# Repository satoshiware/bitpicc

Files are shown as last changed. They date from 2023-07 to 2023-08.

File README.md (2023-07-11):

# Quarter Stick
Bitcoin & microcurrency (SHA256D) Miner - Single ASIC Chip - USB 4.0 (Type C) - Built w\ Eagle

Many thanks to Sidehack (gekkoscience), Kano (cgminer), and Skot (bitaxe)!!
Even though they did not contribute to this project directly, It would not have been possible without their pioneering efforts.

## Setup for Testing Chips
https://youtube.com/watch?v=U-l4Qi08SAI&feature=share

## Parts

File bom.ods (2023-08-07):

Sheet: bm1397
Part | Qty | Value | Device | Package | Manufacture | Mfr. # | Comments | DNP
C1, C2, C3, C4, C5, C6, C7, C8, C9, C10 | 10 | 0.1uF | Ceramic Capacitor | 0402 | KEMET | C0402C104M4PACTU | 16V, X5R, 20%
C13, C14, C15 | 3 | 10uF | Ceramic Capacitor | 0805 | Samsung | CL21A106KOQNNNG | 16V, X5R, 10%
C11, C12, C16, C17, C18, C19, C20, C21, C22, C23, C24, C25, C26, C27, C28, C29 | 16 | 1uF | Ceramic Capacitor | 0603 | KEMET | C0603C105K4RACTU | 16V, X7R, 10%
C30, C31 | 2 | 47pF | Ceramic Capacitor | 0402 | Murata | GRT1555C1H470JA02D | 50V, C0G (NP0), 5%
C32 | 1 | TBD | Capacitor | 1210 | TBD | TBD | Fan | DNP
C33, C34, C35 | 3 | 47uF | Ceramic Capacitor | 1210 | Murata | GRM32EC81C476KE15L | 16V, X6S, 10%, High Capacitance \w Low ESR
C36, C37, C38 | 3 | 100uF | Ceramic Capacitor | 1210 | Murata | GRM32EC70J107ME15K | 6.3V, X7S, 20%, High Capacitance \w Low ESR
C39 | 1 | 3.3nF | Ceramic Capacitor | 0402 | Murata | GRM155R71H332KA01D | 50V, X7R, 10%, DC-DC “Soft-Start”
C40 | 1 | 180pF | Ceramic Capacitor | 0402 | Murata | GRM1555C1H181JA01J | 50V, C0G (NP0), 5%, DC-DC “Compensation Feedback”
C41 | 1 | 1.5nF | Ceramic Capacitor | 0402 | Murata | GRM155R71H152JA01D | 50V, X7R, 5%, DC-DC “Compensation Feedback”
C42 | 1 | 470pF | Ceramic Capacitor | 0402 | Murata | GCM1555C1H471JA16D | 50V, C0G (NP0), 5%, DC-DC “Compensation Feedback”
C43 | 1 | 330uF | Tantalum Capacitor | 3.5 x 2.8 mm | KEMET | T520B337M2R5ATE035 | 2.5V, ESR=35mΩ, 20%
D1 | 1 | Yellow | LED Side Mount | 0805 | Lite-On | LTST-S220KSKT | Clear 587nm
D2 | 1 | Green | LED Side Mount | 0805 | Lite-On | LTST-S220GKT | Clear 569nm
FB1 | 1 | 1.8KΩ | Ferrite Bead | 0402 | Murata | BLM15BD182SN1D | 25%
J1, J2, J3 | 3 | Type C | USB Connector | RA Female | GCT | USB4105-GF-A | 16 (+8 Dummy) SMD Pads, Right Angle, w\ Through Hole Shielding
J4 | 1 | 3 Pin | Fan Connector | Straight Header | Molex | 22-23-2031 | w\ Lock, 0.1” Pitch, Vertical, Tin
L1 | 1 | 150nH @ 0.4 mΩ | Power Inductor | 10.2 x 7.0 mm | Eaton | FP1005R1-R15-R | 47A Flat-Pac FP1005
Q1, Q2 | 2 | N Ch. (0.0023Ω) | Power MOSFET | 8-PowerTDFN | Texas Instruments | CSD17311Q5 | 30V NexFET
Q3 | 1 | NPN | Bipolar Transistor | SOT23 | onsemi | MMBT3904LT3G | 200mA 60V
R1, R2, R3, R4, R5 | 5 | 5.1KΩ | Resistor | 0402 | Bourns | CR0402-FX-5101GLF | Thick Film Resistors 1%
R6 | 1 | 267KΩ | Resistor | 0402 | Bourns | CR0402-FX-2673GLF | Thick Film Resistors 1%
R7 | 1 | 9.1KΩ | Resistor | 0402 | Bourns | CR0402-FX-9101GLF | Thick Film Resistors 1%
R8, R9 | 2 | 27Ω | Resistor | 0402 | Bourns | CR0402-FX-27R0GLF | Thick Film Resistors 1%
R10 | 1 | 4.99KΩ | Resistor | 0402 | Bourns | CR0402-FX-4991GLF | Thick Film Resistors 1%, DC-DC “Feedback Divider”
R11 | 1 | 3.32KΩ | Resistor | 0402 | Bourns | CR0402-FX-3321GLF | Thick Film Resistors 1%, DC-DC “Feedback Divider”
R12 | 1 | 4.12KΩ | Resistor | 0402 | Bourns | CR0402-FX-4121GLF | Thick Film Resistors 1%, DC-DC “Short-Circuit Protection” Configuration
R14 | 1 | 3.83KΩ | Resistor | 0402 | Bourns | CR0402-FX-3831GLF | Thick Film Resistors 1%, DC-DC “Compensation Feedback”
R15 | 1 | 1.33KΩ | Resistor | 0402 | Bourns | CR0402-FX-1331GLF | Thick Film Resistors 1%, DC-DC “Compensation Feedback”
R16 | 1 | 0Ω | Resistor | 0402 | Bourns | CR0402AJ/-000GAS | Thick Film Resistors 5%
R17 | 1 | 100KΩ | Resistor | 0402 | Bourns | CR0402-FX-1003GLF | Thick Film Resistors 1%
R18, R19 | 2 | 300Ω | Resistor | 0402 | Bourns | CR0402-FX-3000GLF | Thick Film Resistors 1%
U1 | 1 | USB 2.0 | UART Bridge IC | 20-QFN (4x4) | FTDI | FT231XQ-R | Full handshake interface
U2 | 1 | 3-20V | DC-DC | 10-VSON | Texas Instruments | TPS40305 | Synchronous Buck Controller
IC1 | 1 | MODE 1 | SHA256D ASIC | 8.1 x 8.1 mm | Bitmain | BM1397 | 7nM S17/T17 Mining Chip
VR1 | 1 | 1.8V | Regulator | 5-TSOP | onsemi | NCP115ASN180T2G | 300 mA CMOS LDO
VR2 | 1 | 0.8V | Regulator | 5-TSOP | onsemi | NCP114ASN080T1G | 300 mA CMOS LDO
Y1 | 1 | 25MHZ | Clock Oscillator | 3.20 x 2.50 mm | Jauch Quartz | O 25,0-JO32-B-1V3-1-T1-LF | H/LV CMOS 1.8V to 3.3V w\ Enable Pin
Order Project – Mouser |  | Total | Total (/Piece)
x1 |  | $32.73 | $32.73
x10 |  | $183.83 | $18.38
x25 |  | $446.70 | $17.87
x50 |  | $788.96 | $15.78
x100 |  | $1,402.26 | $14.02
x500 |  | $5,454.62 | $10.91
x1000 |  | $10,256.31 | $10.26
Quote Excludes: |  | BM1397 (IC1) | Aliexpress ($1.60 Used; w\ 100 piece order)
 |  | Clock Oscillator (Y2) | Digikey ($0.61 w\ 100 piece order)
Order Project – Digikey |  | Total | Total (/Piece)
x1 |  | $34.03 | $34.03
x10 |  | $210.33 | $21.03
x25 |  | $484.32 | $19.37
x50 |  | $859.97 | $17.20
x100 |  | $1,551.99 | $15.52
x500 |  | $6,037.49 | $12.07
x1000 |  | $10,777.23 | $10.78
Quote Excludes: |  | BM1397 (IC1) | Aliexpress ($1.60 Used; w\ 100 piece order)
Last Update: |  | 07/08/23
Tax, Tarrifs, & Shipping included in both quotes

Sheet: PCBWay
High Reliability and a guaranteed/durable PCB
Link: | https://www.pcbway.com/HighQualityOrderOnline.aspx
PCB Type: | Through hole board
Board Spec: | IPC 6012 Class 3
Board Type: | Single pieces
Different Design in Panel: | 1
Size: | 55 x 60 mm | Cost | Cost (/Piece)
Quantity: | 10 | $278.37 | $27.84
 | 50 | $346.71 | $6.93
 | 100 | $437.46 | $4.37
 | 500 | $955.82 | $1.91
 | 1000 | $1,830.44 | $1.83
Layers: | 4
Material: | Tg150 FR-4 | Note: Cost includes shipping and stencil
Thickness: | 1.2 mm | Last Update: 06/27/2023
Min Track/Spacing: | 3/3 mil
Min Hole Size: | 0.15 mm
Solder Mask: | Red
Silkscreen: | White
Edge Connector: | No
Surface Finish: | Immersion Gold (ENIG)
Thickness of Immersion Gold: | 3U”
Finished Copper: | 1 oz
Inner Copper | 1 oz
SMD-Stencil
Stencil Type: | Non-framework
Size (mm) | 370 x 470 mm (Valid Area 190 x 290 mm)
Stencil Side: | Top+Bottom (On Single Stencil)
Quantity: | 1
Thickness: | 0.12 mm
Existing Fiducials: | Half-Lasered
Electropolishing: | No

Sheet: Support
Hardware | Cost | Description | Link
Cooling | $2.99 | 5V 3 Pin Fan w\ Heatsink (40 x 40 mm) | https://www.aliexpress.us/item/2255801019498718.html?_t=pvid%3Ab1a72f07-dc0e-411c-90b8-5922d5adfd63
Power Supply | $10.99 | iUniker 20W USB C Power Supply \w ON/Off Switch 5V @ 4A | https://www.amazon.com/dp/B097P2NLVH?ref_=cm_sw_r_mwn_dp_BKBT72C03QF0A4G42ZP8
 | $4.90 | 5V @ 4A | https://www.aliexpress.us/item/3256804431854441.html?curPageLogUid=AsnPRPA31Hv0
 | $2.48 | 5V @ 4A | https://www.aliexpress.us/item/3256804892421649.html?scm_id=1007.40000.326746.0&scm-url=1007.40000.326746.0
Data Cable | $2.59 | USB Type-A to Type-C 6ft Cable (5 Pack) | https://www.amazon.com/Charging-Charger-Compatible-Samsung-Braided/dp/B082Z1YYRK
BM1397 (new) | $7.00 | SHA256D ASIC by Bitmain 7nM S17/T17 Mining Chip | https://www.aliexpress.us/item/3256804044794770.html?_t=pvid%3A609b266e-81d6-4e67-aa0f-3d1761e4ddf2
BM1397 (used) | $1.60 | SHA256D ASIC by Bitmain 7nM S17/T17 Mining Chip | https://www.aliexpress.us/item/3256804983573537.html?_t=pvid%3A3617358f-637e-43ee-87aa-40acbc3eb248
Spacer (Feet) x3 | $2.40 | Stainless Steel Round, Length = 13 mm (~0.5”) , Thread = M3 , Diameter = 6 mm | https://www.mouser.com/ProductDetail/RAF-Electronic-Hardware/M0542-3-SS?qs=dwkm%252BGAHGA1%2FNOqA2JHU6A%3D%3D
 | $1.13 | Stainless Steel Hex, Length = 14 mm (~0.55”) , Thread = M3 , Diameter = 6 mm | https://www.amazon.com/UNICORP-MP1027-M09-F16-M3-Threaded-Standoff-Stainless/dp/B01HZQN62K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
 | $2.95 | Stainless Steel Hex, Length = 12 mm (~0.47”) , Thread = M3 , Diameter = 6 mm | https://www.digikey.com/en/products/detail/raf-electronic-hardware/M1309-3005-SS/7681047
M3 Screws | $0.24 | M3x5 Round Head PC Screws (Nickel Plated) | https://www.amazon.com/Honbay-100PCS-Mounting-Computer-Motherboard/dp/B09YCWL8FX?hvadid=658211984123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
 |  |  | https://www.amazon.com/VizGiz-Mounting-Phillips-Computer-Motherboard/dp/B09XBC3GV5?hvadid=580876141803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
Non-Essentials
USB C to Micro Cable(s) | $5.93 | USB C to Micro USB Cable 1FT (3 Pack) – Quantity 2 | https://www.amazon.com/gp/product/B0BR3RXS7S/ref=ox_sc_act_title_2?smid=A31U33AKI1FXJJ
Micro SD (8 GB) | $2.70 | 8GB Micro SD Card (20 Pack) | https://www.amazon.com/gp/product/B085ZW6W12/ref=ox_sc_act_title_4?smid=A21AQ316WNX0L1&psc=1
RPi Zero W | $15.00 | Raspberry Pi Zero W (WIFI) | https://www.pishop.us/product/raspberry-pi-zero-w/
Fan Upgrade | $13.95 | Noctua NF-A4x10 Premium Quiet Fan (3-Pin @ 5V) | https://www.amazon.com/Noctua-Cooling-Bearing-NF-A4X10-FLX-5V/dp/B00NEMGCIA
Last Update: 06/21/2023

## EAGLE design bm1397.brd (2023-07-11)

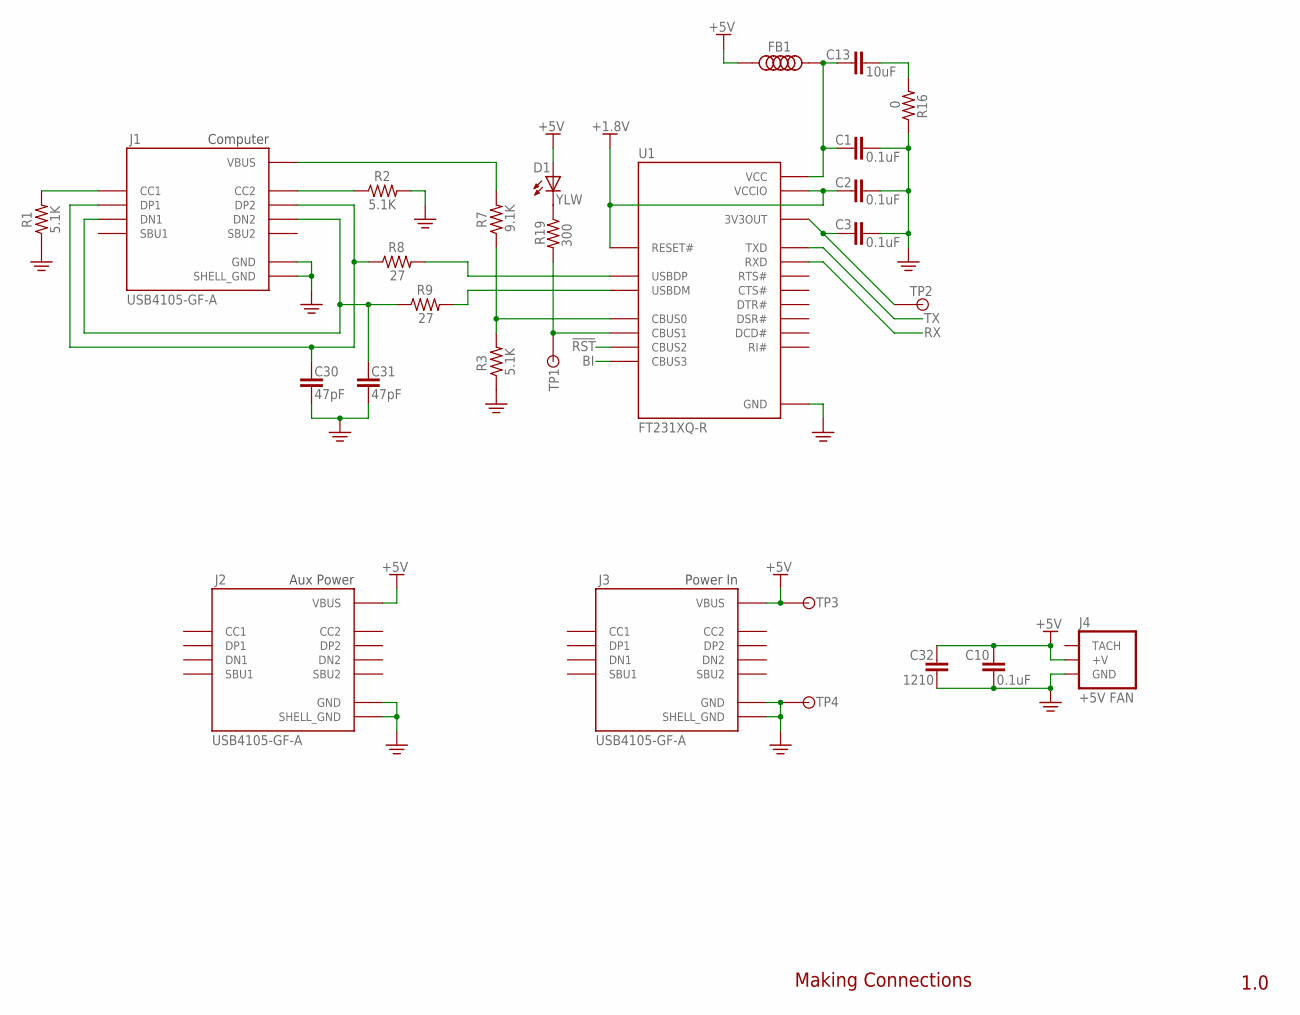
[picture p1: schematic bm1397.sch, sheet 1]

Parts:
C1, C2, C3, C10: 0.1uF; C0402
C13: 10uF; C0805
C30, C31: 47pF; C0402
C32: 1210; C1210
D1: YLW; 0805_SD_MNT
FB1: FERRITE_BEADF0402; F0402
J1, J2, J3: USB4105-GF-A; GCT_USB4105-GF-A
J4: +5V FAN; 3PIN_LOCK_HEADER
R1, R2, R3: 5.1K; R0402
R7: 9.1K; R0402
R8, R9: 27; R0402
R16: 0; R0402
R19: 300; R0402
TP1, TP2, TP3, TP4: TESTPOINT; 0.035
U1: FT231XQ-R; QFN50P400X400X80-21N

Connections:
!RST: U1.7 (CBUS2); also elsewhere on the board
+1V8: C2.1, U1.11 (RESET#), U1.20 (VCCIO); also elsewhere on the board
+5V: C10.2, C32.1, D1.A, FB1.1, J2.A4_B9 (VBUS), J2.B4_A9 (VBUS), J3.A4_B9 (VBUS), J3.B4_A9 (VBUS), J4.2 (+V), TP3.TP; also elsewhere on the board
BI: U1.16 (CBUS3); also elsewhere on the board
CC1: J1.A5 (CC1), R1.2
CC2: J1.B5 (CC2), R2.1
FB+5V: C1.1, C13.1, FB1.2, U1.12 (VCC)
GND: C1.2, C2.2, C3.2, C10.1, C30.1, C31.1, C32.2, J1.A1_B12 (GND), J1.B1_A12 (GND), J1.S1 (SHELL_GND), J1.S2 (SHELL_GND), J1.S3 (SHELL_GND), J1.S4 (SHELL_GND), J2.A1_B12 (GND), J2.B1_A12 (GND), J2.S1 (SHELL_GND), J2.S2 (SHELL_GND), J2.S3 (SHELL_GND), J2.S4 (SHELL_GND), J3.A1_B12 (GND), J3.B1_A12 (GND), J3.S1 (SHELL_GND), J3.S2 (SHELL_GND), J3.S3 (SHELL_GND), J3.S4 (SHELL_GND), J4.1 (GND), R1.1, R2.2, R3.1, R16.1, TP4.TP, U1.3 (GND), U1.13 (GND), U1.21 (GND); also elsewhere on the board
unnamed: C13.2, R16.2
unnamed: R8.2, U1.8 (USBDP)
unnamed: C30.2, J1.A6 (DP1), J1.B6 (DP2), R8.1
unnamed: C31.2, J1.A7 (DN1), J1.B7 (DN2), R9.1
unnamed: D1.C, R19.1
unnamed: R9.2, U1.9 (USBDM)
unnamed: R3.2, R7.1, U1.15 (CBUS0)
unnamed: J1.A4_B9 (VBUS), J1.B4_A9 (VBUS), R7.2
unnamed: C3.1, TP2.TP, U1.10 (3V3OUT)
unnamed: R19.2, TP1.TP, U1.14 (CBUS1)
RX: U1.1 (RXD); also elsewhere on the board
TX: U1.17 (TXD); also elsewhere on the board

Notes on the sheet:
Computer
Power In
1.0
Making Connections
Aux Power

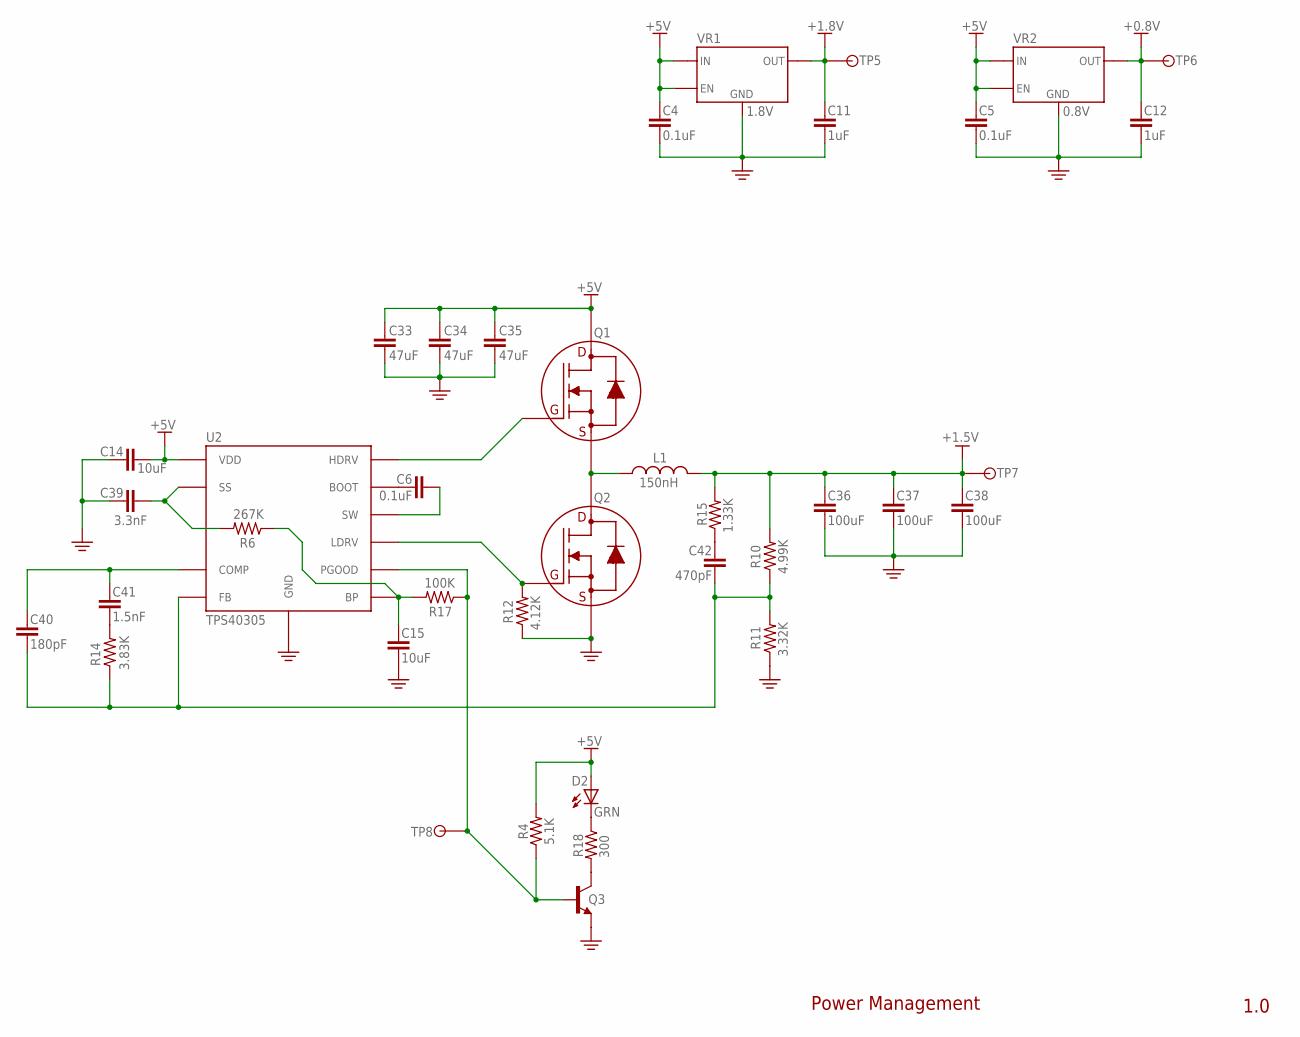
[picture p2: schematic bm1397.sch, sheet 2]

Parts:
C4, C5, C6: 0.1uF; C0402
C11, C12: 1uF; C0603
C14, C15: 10uF; C0805
C33, C34, C35: 47uF; C1210
C36, C37, C38: 100uF; C1210
C39: 3.3nF; C0402
C40: 180pF; C0402
C41: 1.5nF; C0402
C42: 470pF; C0402
D2: GRN; 0805_SD_MNT
L1: 150nH; 10.2MMX7.0MM
Q1, Q2: 8-PowerTDFN; CSD17311Q5
Q3: NPN; SOT23
R4: 5.1K; R0402
R6: 267K; R0402
R10: 4.99K; R0402
R11: 3.32K; R0402
R12: 4.12K; R0402
R14: 3.83K; R0402
R15: 1.33K; R0402
R17: 100K; R0402
R18: 300; R0402
TP5, TP6, TP7, TP8: TESTPOINT; 0.035
U2: TPS40305
VR1: 1.8V; TSOP-5
VR2: 0.8V; TSOP-5

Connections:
+0V8: C12.1, TP6.TP, VR2.5 (OUT); also elsewhere on the board
+1V5: C36.1, C37.1, C38.1, L1.2, R10.2, R15.2, TP7.TP; also elsewhere on the board
+1V8: C11.1, TP5.TP, VR1.5 (OUT); also elsewhere on the board
+5V: C4.1, C5.1, C14.1, C33.1, C34.1, C35.1, D2.A, Q1.5 (D), Q1.6 (D), Q1.7 (D), Q1.8 (D), Q1.9 (D), R4.2, U2.1 (VDD), VR1.1 (IN), VR1.3 (EN), VR2.1 (IN), VR2.3 (EN); also elsewhere on the board
BP: C15.1, R6.1, R17.2, U2.10 (BP)
GND: C4.2, C5.2, C11.2, C12.2, C14.2, C15.2, C33.2, C34.2, C35.2, C36.2, C37.2, C38.2, C39.2, Q2.1 (S), Q2.2 (S), Q2.3 (S), Q3.2 (E), R11.1, R12.1, U2.11 (GND), U2.12 (GND), U2.13 (GND), U2.14 (GND), U2.15 (GND), VR1.2 (GND), VR2.2 (GND); also elsewhere on the board
HDRV: Q1.4 (G), U2.7 (HDRV)
LDRV: Q2.4 (G), R12.2, U2.9 (LDRV)
LIN: L1.1, Q1.1 (S), Q1.2 (S), Q1.3 (S), Q2.5 (D), Q2.6 (D), Q2.7 (D), Q2.8 (D), Q2.9 (D)
unnamed: C40.1, C41.1, U2.4 (COMP)
unnamed: C41.2, R14.2
unnamed: C6.2, U2.6 (BOOT)
unnamed: C6.1, U2.8 (SW)
unnamed: C42.1, R15.1
unnamed: C40.2, C42.2, R10.1, R11.2, R14.1, U2.5 (FB)
unnamed: D2.C, R18.1
unnamed: Q3.3 (C), R18.2
PGOOD: Q3.1 (B), R4.1, R17.1, TP8.TP, U2.3 (PGOOD)
SS: C39.1, R6.2, U2.2 (SS)

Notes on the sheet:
1.0
Power Management

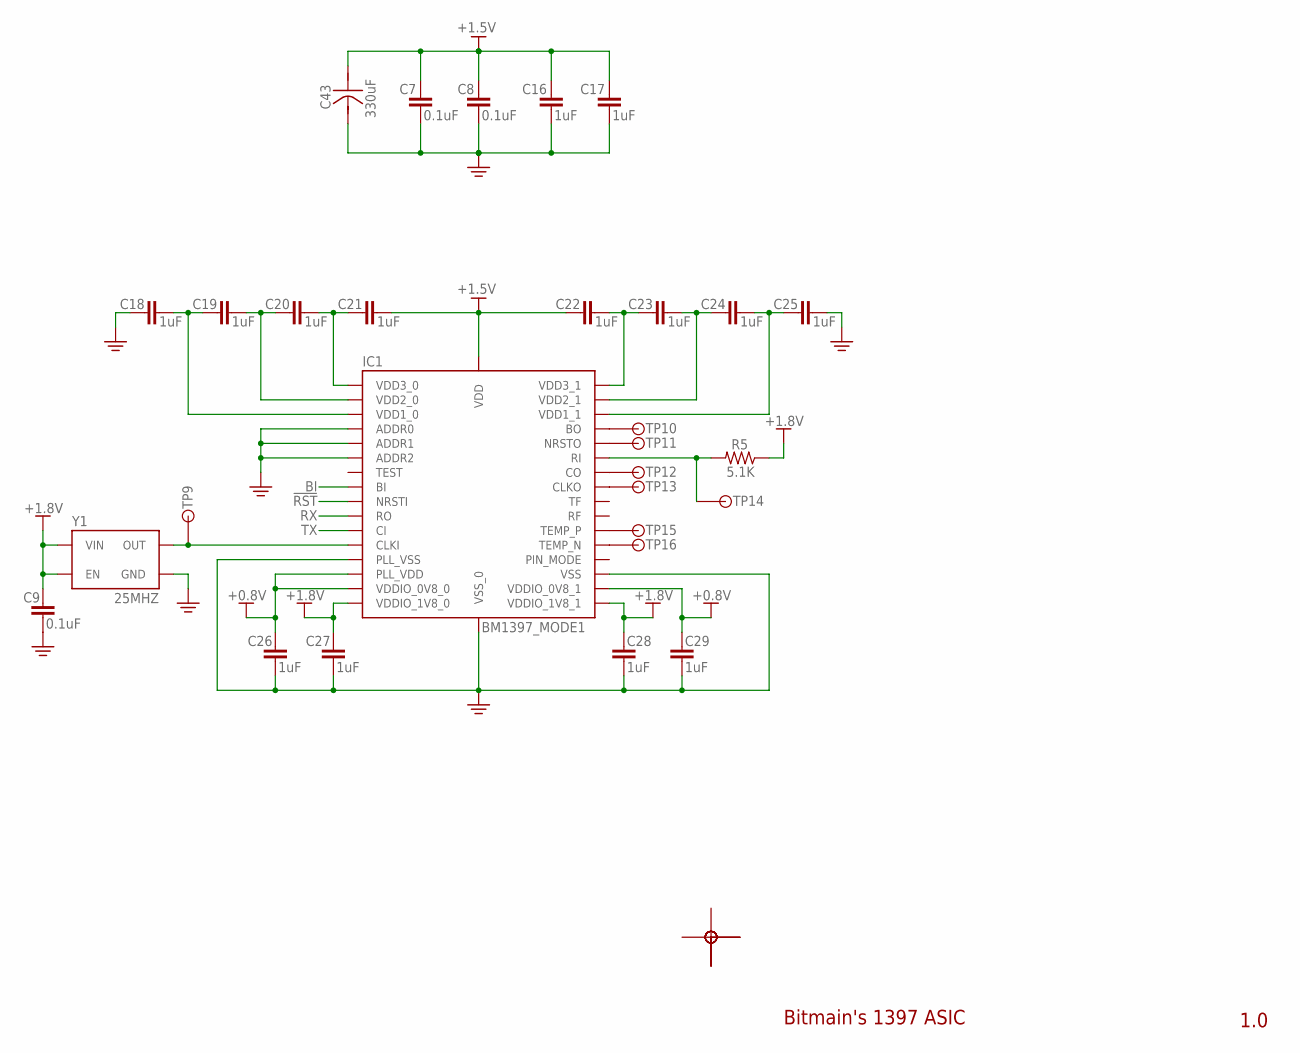
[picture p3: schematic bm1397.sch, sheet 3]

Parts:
BOTFIDUCIAL1, BOTFIDUCIAL2, BOTFIDUCIAL3: TESTPOINT; 0.035
C7, C8, C9: 0.1uF; C0402
C16, C17, C18, C19, C20, C21, C22, C23, C24, C25, C26, C27, C28, C29: 1uF; C0603
C43: 330uF; TANT_3.5MMX2.8MM
IC1: BM1397_MODE1; BM1397
R5: 5.1K; R0402
TOPFIDUCIAL1, TOPFIDUCIAL2, TOPFIDUCIAL3: TESTPOINT; 0.035
TP9, TP10, TP11, TP12, TP13, TP14, TP15, TP16: TESTPOINT; 0.035
Y1: 25MHZ; JO32_3.20MMX2.50MM

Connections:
!RST: IC1.9 (NRSTI); also elsewhere on the board
+0V8: C26.1, C29.1, IC1.14 (PLL_VDD), IC1.15 (VDDIO_0V8_0), IC1.18 (VDDIO_0V8_1); also elsewhere on the board
+1V5: C7.2, C8.2, C16.2, C17.2, C21.2, C22.2, C43.A (+), IC1.33 (VDD); also elsewhere on the board
+1V8: C9.2, C27.1, C28.1, IC1.16 (VDDIO_1V8_0), IC1.17 (VDDIO_1V8_1), R5.1, Y1.1 (EN), Y1.4 (VIN); also elsewhere on the board
BI: IC1.8 (BI); also elsewhere on the board
CLK: IC1.12 (CLKI), TP9.TP, Y1.3 (OUT)
GND: C7.1, C8.1, C9.1, C16.1, C17.1, C18.1, C25.1, C26.2, C27.2, C28.2, C29.2, C43.C (-), IC1.4 (ADDR0), IC1.5 (ADDR1), IC1.6 (ADDR2), IC1.13 (PLL_VSS), IC1.19 (VSS), IC1.34 (VSS_0), Y1.2 (GND); also elsewhere on the board
unnamed: BOTFIDUCIAL2.TP, TOPFIDUCIAL1.TP
unnamed: C19.2, C20.1, IC1.2 (VDD2_0)
unnamed: BOTFIDUCIAL3.TP, TOPFIDUCIAL3.TP
unnamed: C18.2, C19.1, IC1.3 (VDD1_0)
unnamed: C20.2, C21.1, IC1.1 (VDD3_0)
unnamed: C22.1, C23.2, IC1.32 (VDD3_1)
unnamed: C23.1, C24.2, IC1.31 (VDD2_1)
unnamed: C24.1, C25.2, IC1.30 (VDD1_1)
unnamed: IC1.21 (TEMP_N), TP16.TP
unnamed: IC1.22 (TEMP_P), TP15.TP
unnamed: IC1.25 (CLKO), TP13.TP
unnamed: IC1.26 (CO), TP12.TP
unnamed: IC1.27 (RI), R5.2, TP14.TP
unnamed: IC1.28 (NRSTO), TP11.TP
unnamed: IC1.29 (BO), TP10.TP
RX: IC1.10 (RO); also elsewhere on the board
TX: IC1.11 (CI); also elsewhere on the board

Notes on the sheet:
1.0
Bitmain's 1397 ASIC

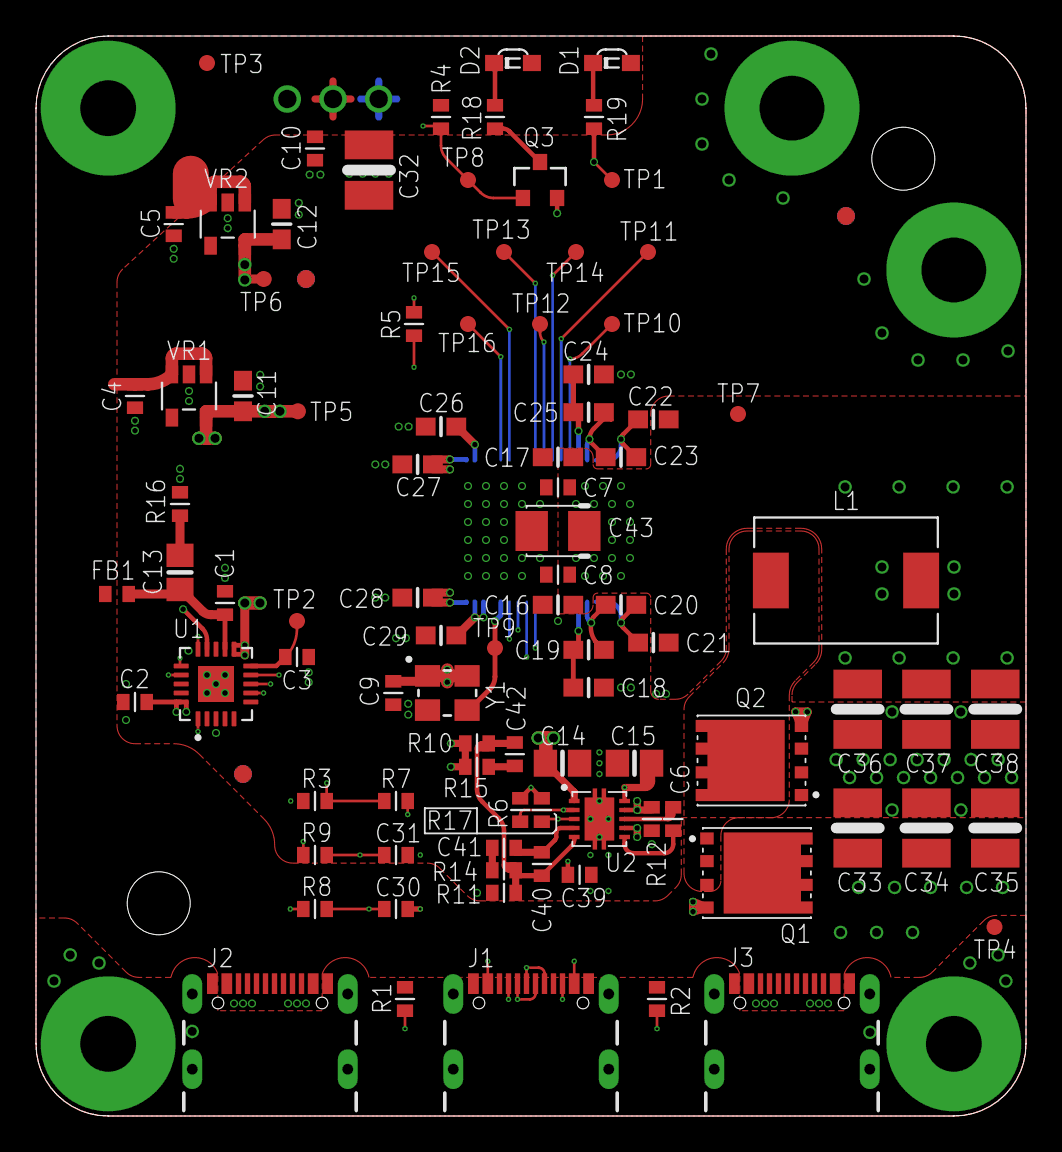
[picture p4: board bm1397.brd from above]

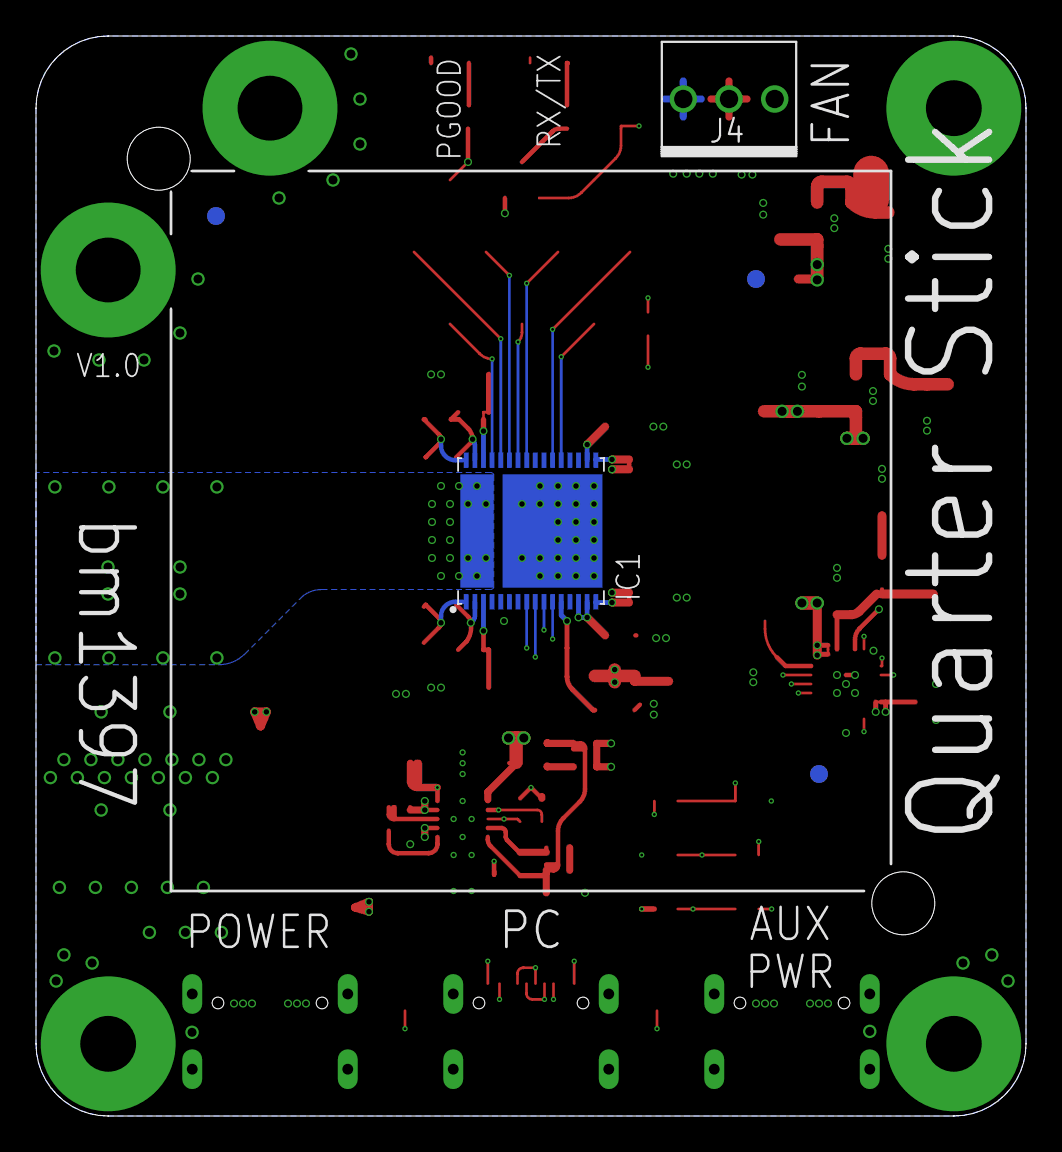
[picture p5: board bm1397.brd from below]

Board: 4 copper layers, 55.0 x 60.0 mm, 100 parts (5 on the bottom side), 52 nets.

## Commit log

2023-07-11 Changed name to "Quarter Stick"
    [bm1397.brd]
2023-08-07 Updated Fan Connector
    [bom.ods]
2023-08-07 Updated Fan Connector: 22-23-2031
    [bom.ods]
